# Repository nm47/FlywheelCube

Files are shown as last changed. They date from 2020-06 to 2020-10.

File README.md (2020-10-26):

# Flywheel Cube
 A reaction wheel LQR balanced cube using the teensy 3.5
 
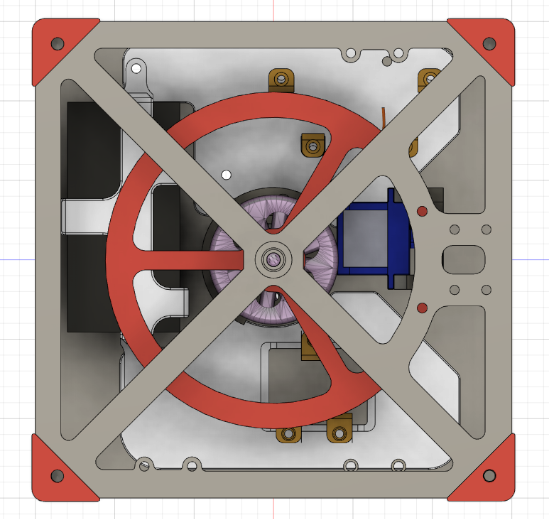
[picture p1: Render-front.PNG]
Cube Picture Alt
 
 
#### Note: This project is a work in progress, the current status can be found under "Roadmap".

## Installation
Simply Download the zip and run, PID/Kalman tuning parameters can be found in the Cube.cpp file.

Note: This project was designed to run on the Teensy3.5. Other versions of the teensy will require slight wiring modifications as the 3.5 is 5v tolerant on most pins and others are not. 

TeensyDuino must be installed to program the teensy through the arduino IDE.
TeensyDuino can be found here:

https://www.pjrc.com/teensy/td_download.html

## Roadmap
#### Todo:

- Trajectory prediction on popup, cube must repeatedly pop up within a range of ~15 degrees.  
- Implement PID to control flywheel speed during balancing phase (after popup).
- Test and fine tune braking assembly

#### Complete: 
- Improve startup sequence to reduce heat generated by the motor.
- Improve the grip of the rubber corners to reduce the effect of different surfaces on pop-up power.
- Read and filter values from the MPU6050.
- Account for different battery voltages during initial pop-up stage.
- CAD/Electronic design.
- Control the H-bridge on the ESC with the teensy.
- Build an encoder to detect position and speed of the motor.

## Meta

Niels Moeller – NielsMoeller9@gmail.com

Distributed under the MIT license. See ``LICENSE`` for more information.

https://github.com/nm47/FlywheelCube/blob/master/License.txt

## Contributing

1. Fork it (<https://github.com/nm47/FlywheelCube/fork>)
2. Create your feature branch (`git checkout -b feature/fooBar`)
3. Commit your changes (`git commit -am 'Add some fooBar'`)
4. Push to the branch (`git push origin feature/fooBar`)
5. Create a new Pull Request

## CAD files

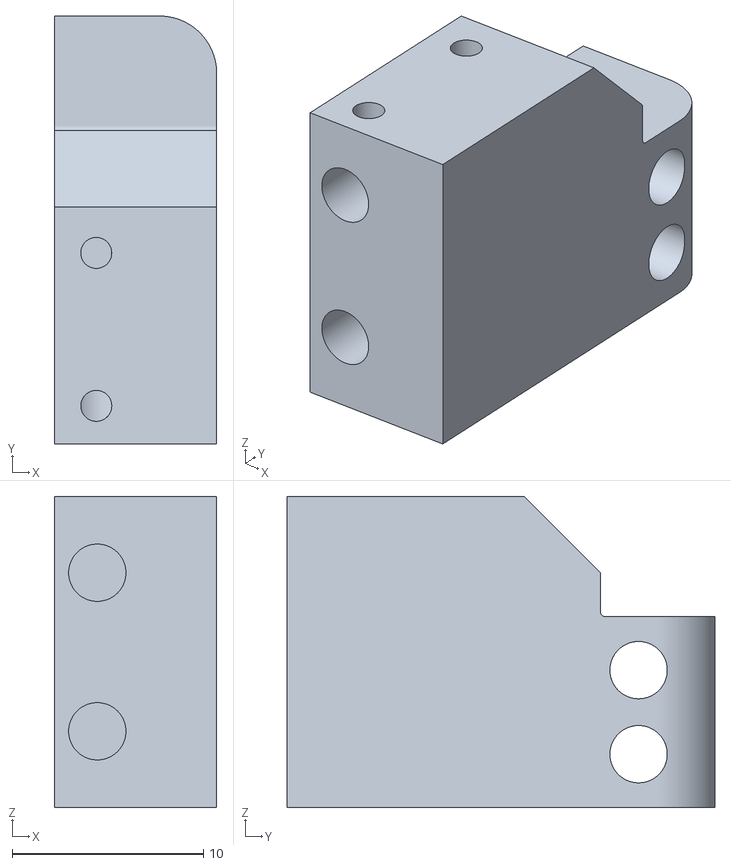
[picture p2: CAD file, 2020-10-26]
CAD/STL/Brake Mount Left.stl
8.50 x 22.4 x 16.3

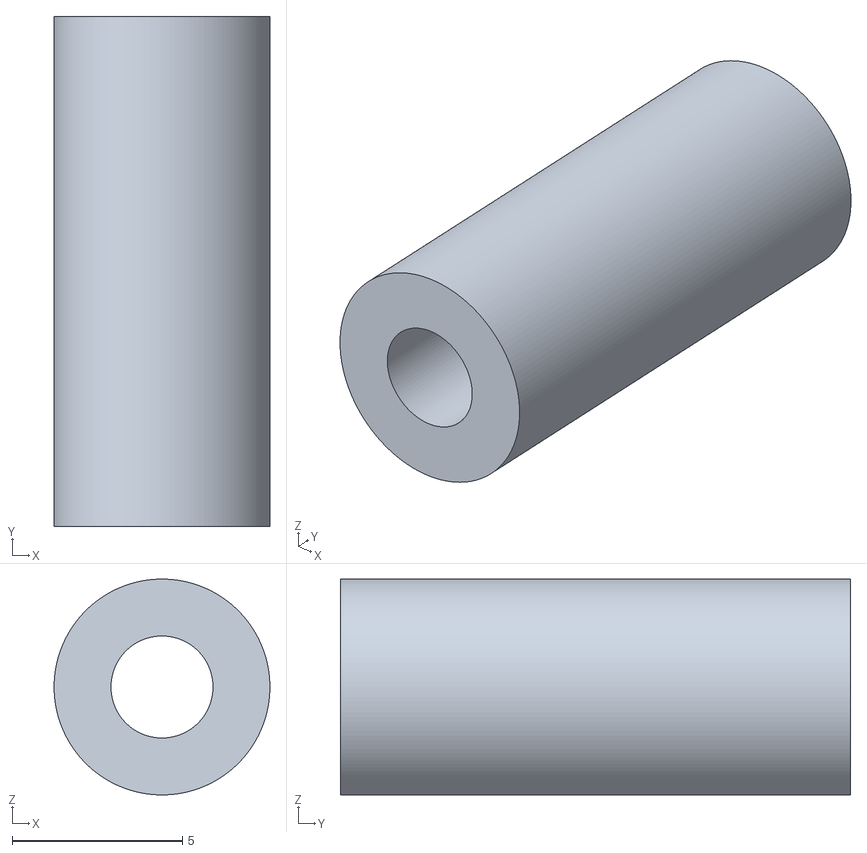
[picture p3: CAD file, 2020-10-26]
CAD/STL/Brake piston.stl
6.35 x 15.0 x 6.35

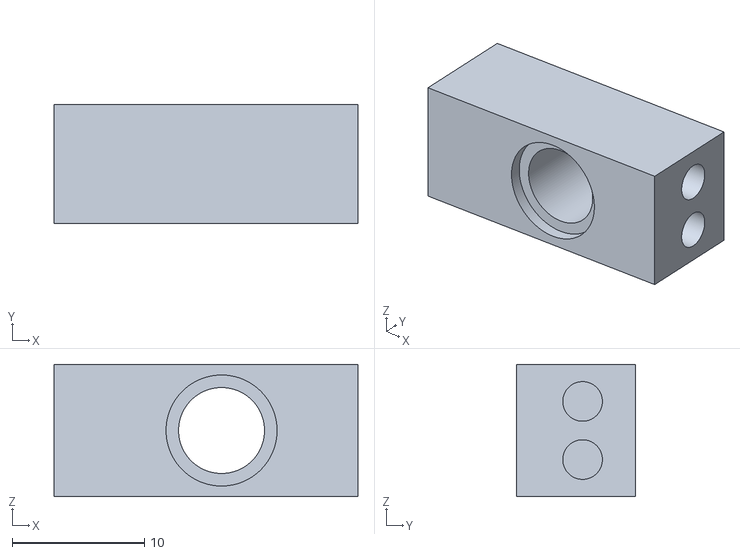
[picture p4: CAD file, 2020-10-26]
CAD/STL/Brake bushing.stl
23.0 x 9.00 x 10.00

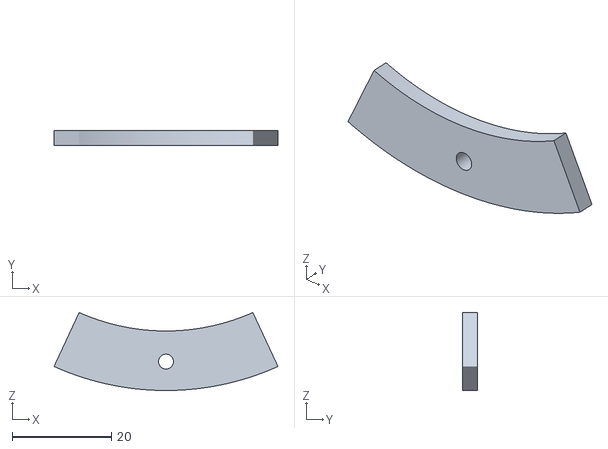
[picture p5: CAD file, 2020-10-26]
CAD/STL/Brake Plate.stl
45.2 x 3.00 x 15.7

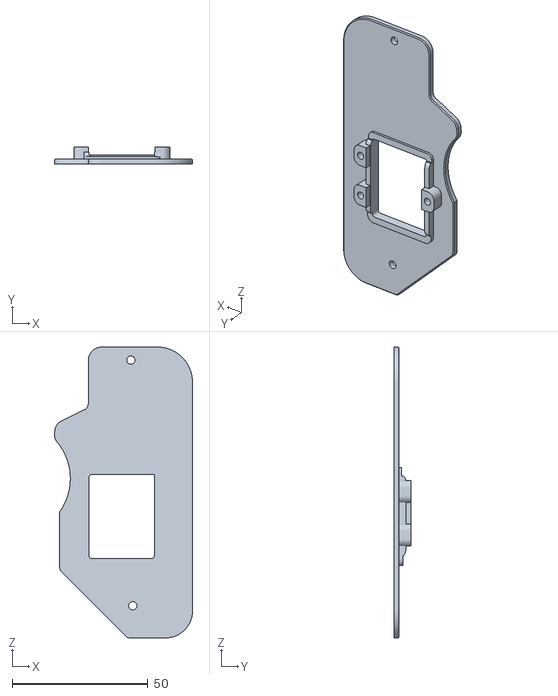
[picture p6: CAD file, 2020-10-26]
CAD/STL/PCB Plate R.stl
50.9 x 6.40 x 107.2

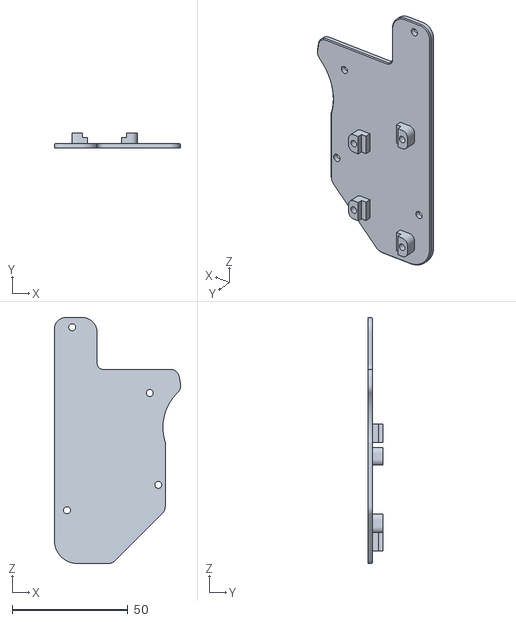
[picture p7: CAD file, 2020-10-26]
CAD/STL/PCB Plate L.stl
54.5 x 6.40 x 106.2

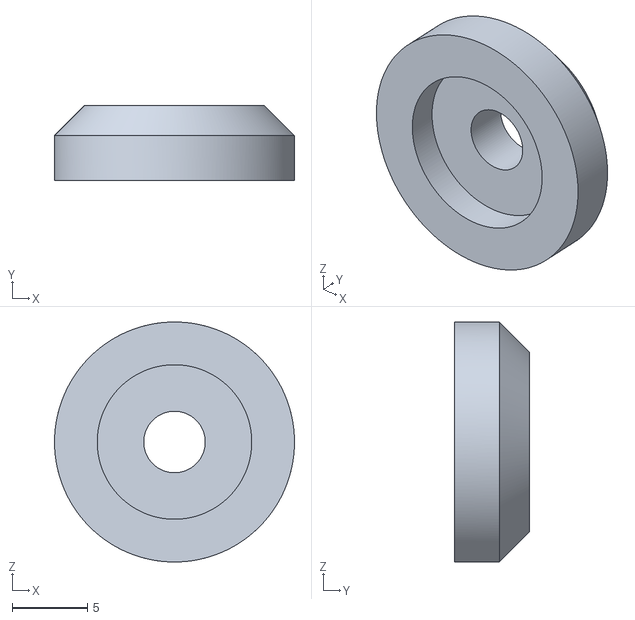
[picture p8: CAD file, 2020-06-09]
CAD/STL/FlyWheel Clamp.stl
16.0 x 5.00 x 16.0

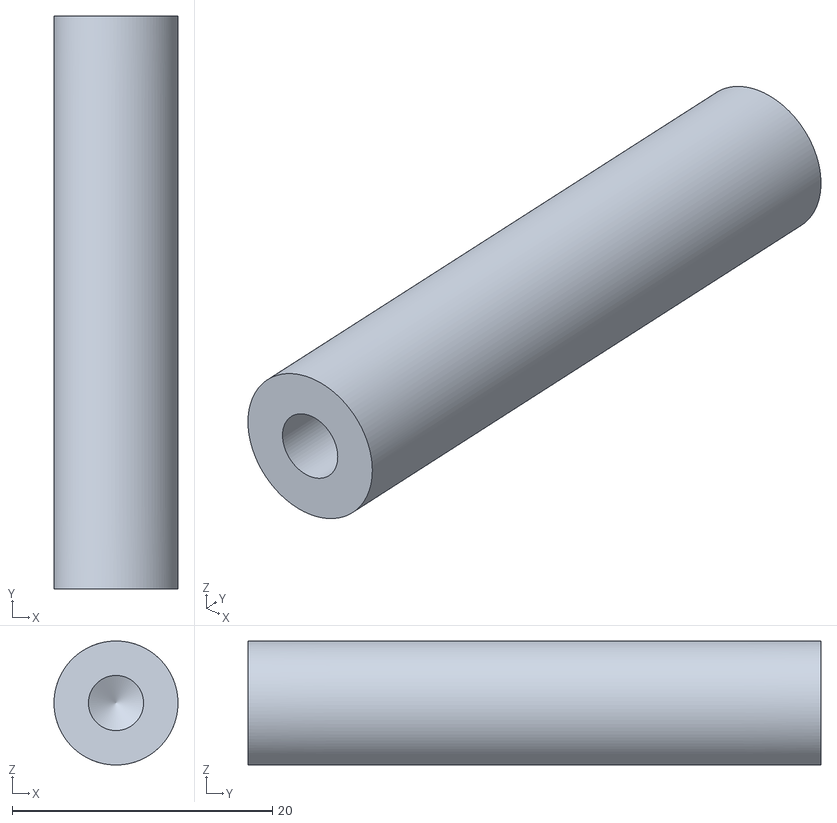
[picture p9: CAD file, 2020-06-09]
CAD/STL/Column.stl
9.53 x 44.0 x 9.52

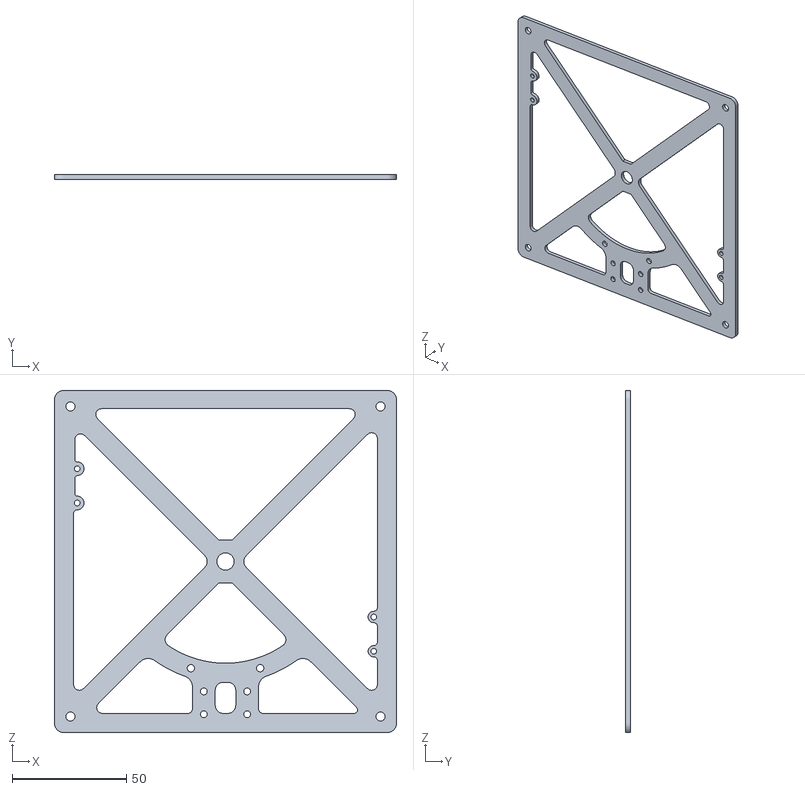
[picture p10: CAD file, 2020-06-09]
CAD/STL/Faceplate.stl
150.0 x 2.00 x 150.0

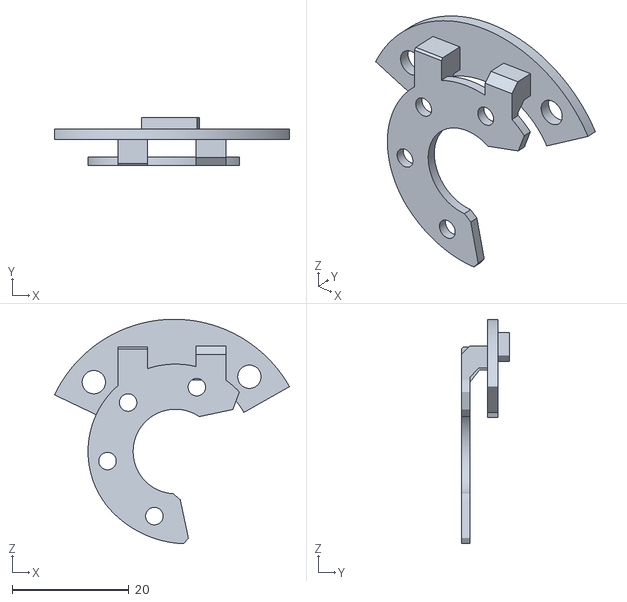
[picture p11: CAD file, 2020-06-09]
CAD/STL/Encoder Mount .stl
40.3 x 8.30 x 38.5

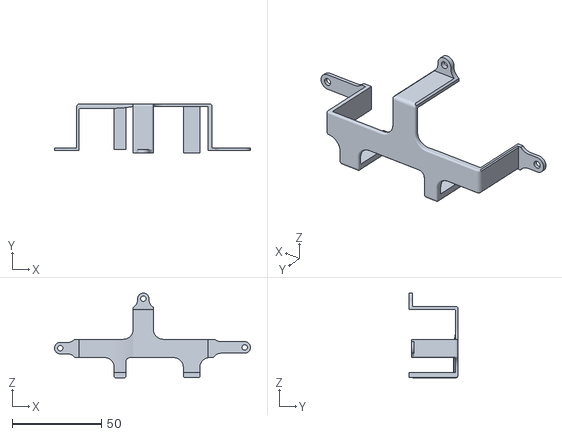
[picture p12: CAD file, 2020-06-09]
CAD/STL/Battery Holder.stl
110.0 x 27.7 x 47.7

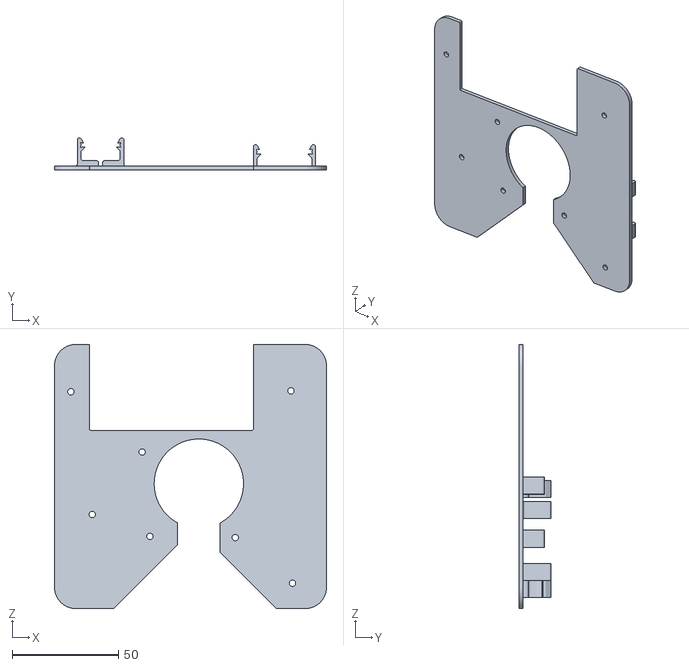
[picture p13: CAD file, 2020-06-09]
CAD/STL/PCB Mounting Plate.stl
127.9 x 15.2 x 124.2

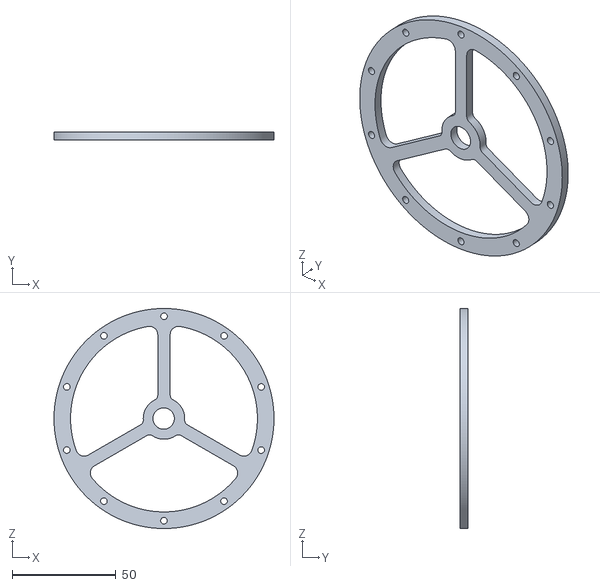
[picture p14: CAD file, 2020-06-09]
CAD/STL/FlyWheel.stl
106.0 x 4.00 x 106.0

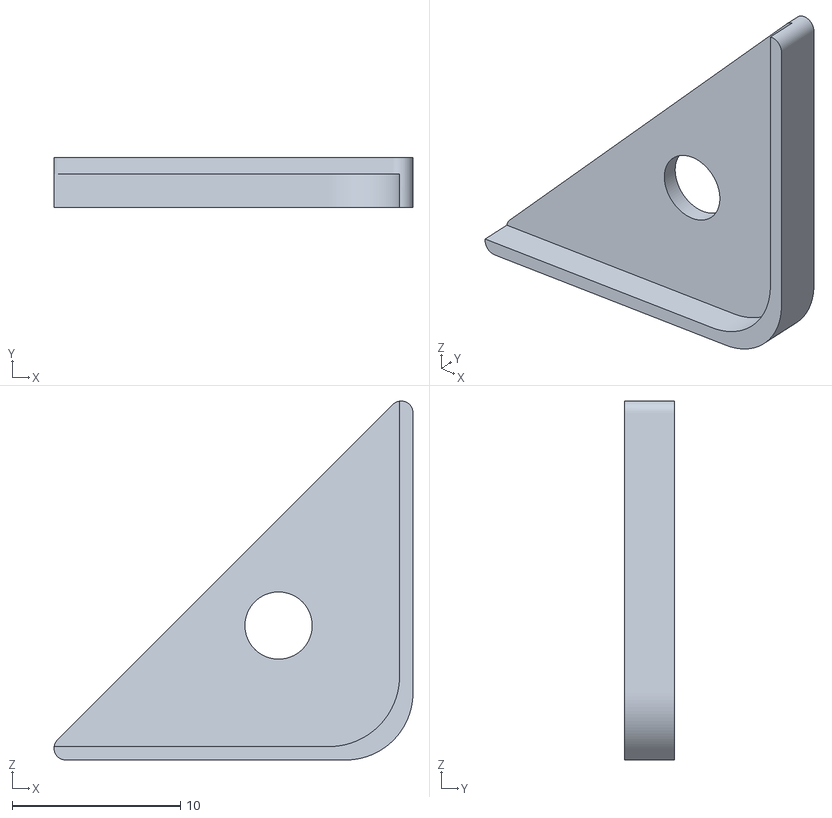
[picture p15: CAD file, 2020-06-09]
CAD/STL/Rubber Corner Grip.stl
21.4 x 3.00 x 21.4

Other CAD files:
CAD/STL/Brake Mount Right.stl
CAD/STL/Backplate.stl

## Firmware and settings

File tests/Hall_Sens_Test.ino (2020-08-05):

// USAGE:
// The goal of this program is to verify that your hall sensors
// are connected correctly, as well as positioned correctly.
// spinning clockwise, you should see the following sequence of bits
// being output to the serial monitor: 101 001 011 010 110 100
// each of the 3 bits represents a hall sensor, 1 is high,0 is low.
// Note: in the full cube program, the hall sensors are on interrupts rather than a busy loop.
//TROUBLESHOOTING:
// If you do not see the correct output,your hall sensors are likely
// positioned or wired incorrectly. This can be corrected using an oscilloscope
// as shown in the project repository on GitHub.

// If 1, states will be output numerically, ie. 3 instead of 011
#define NUMERICAL_STATES 0

//define hall Sensor pins
const short HA = 2;
const short HB = 3;
const short HC = 4;

short state = -1;
void setup() {
  Serial.begin(115200);

  // The A1304 output pin must be pulled up to 3.3v
  pinMode(HA, INPUT_PULLUP);
  pinMode(HB, INPUT_PULLUP);
  pinMode(HC, INPUT_PULLUP);
  pinMode(13, OUTPUT);

  delay(1000);
  // turn on the on-board LED to indicate logging has started.
  digitalWrite(13, HIGH);
}

// Get the current state of the hall sensors.
// if the state has changed we must commutate windings.
void loop() {
  int new_state = GetHallState();
  if (state != new_state) {
    if (NUMERICAL_STATES)
      Serial.println(new_state);
    state = new_state;
  }
}

// Returns the current position of the rotor.
// -1 should not be possible, if hall sensors don't match the 6 steps E-Stop.
short GetHallState() {
  int hallA = digitalRead(HA);
  int hallB = digitalRead(HB);
  int hallC = digitalRead(HC);

  if (!NUMERICAL_STATES) {
    Serial.print(hallA);
    Serial.print(hallB);
    Serial.println(hallC);
  }
  // Converts hall sensor readings to numerical states
  // 101 001 011 010 110 100
  if (hallA && !hallB && hallC)
    return 1;
  else if (!hallA && !hallB && hallC)
    return 2;
  else if (!hallA && hallB && hallC)
    return 3;
  else if (!hallA && hallB && !hallC)
    return 4;
  else if (hallA && hallB && !hallC)
    return 5;
  else if (hallA &&  !hallB && !hallC)
    return 6;
  else {
    // This should never happen, if it somehow does, states of the hall sensors are
    // printed at the time of failure for debugging purposes. This also calls
    // the emergency stop in the full program.
    Serial.print(hallA);
    Serial.print(hallB);
    Serial.println(hallC);
  }
}

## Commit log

2020-04-26 Board Outline and stencil for alignment in KiCAD
    [SMDHALL.dxf, SMDHALL_Stencil.dxf]
2020-04-28 Added sketch files for use in fusion360
    files to design a mount around
2020-04-29 FIXED: Only export board area
2020-06-09 Added STLs of all Components under STL
    [Backplate.stl, Battery Holder.stl, Column.stl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]
2020-06-30 Initial upload
    [Encoder-B_Cu.gbr, Encoder-B_Mask.gbr, Encoder-B_Paste.gbr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]
2020-07-01 Mounting plate now split into two pieces
    Split the mounting plate into two pieces and modified the PCB mounts. PCBs are now screwed into brass inserts in the PCB plates. This fixed an issue with the mounts snapping when removing boards, as well as making it easier to remove the motor.
    [PCB Plate L.stl, PCB Plate R.stl]
2020-07-01 dxf of board and components
2020-07-01 Remove old board files for v2 encoder
2020-07-01 Remove v2 encoder files
2020-08-05 Added Hall Sensor Test
2020-08-05 Add Hall Sensor Test
2020-08-13 Barebones Kalman Filter implementation
2020-08-21 Basic PID Controller
2020-09-27 Add picture of CAD model
2020-10-26 Modified to make space for braking assembly
    [PCB Plate L.stl, PCB Plate R.stl]
2020-10-26 Create Braking Assembly
    [Brake Mount Left.stl, Brake Mount Right.stl, Brake Plate.stl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]
2020-10-26 Add braking assembly to todo, fixed motor startup
